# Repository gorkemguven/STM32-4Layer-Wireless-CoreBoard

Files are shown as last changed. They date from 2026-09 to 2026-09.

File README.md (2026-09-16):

# STM32 4-Layer Wireless Core Board

A compact, 4-layer reusable STM32 wireless core board designed in KiCad. It functions both as a standalone USB-to-Wireless dongle/sniffer and as a modular core block for integration into larger IoT and embedded carrier boards.

---

## 📌 Board Overview

| 3D / Top Layer View | Inner Ground Plane |
| :---: | :---: |
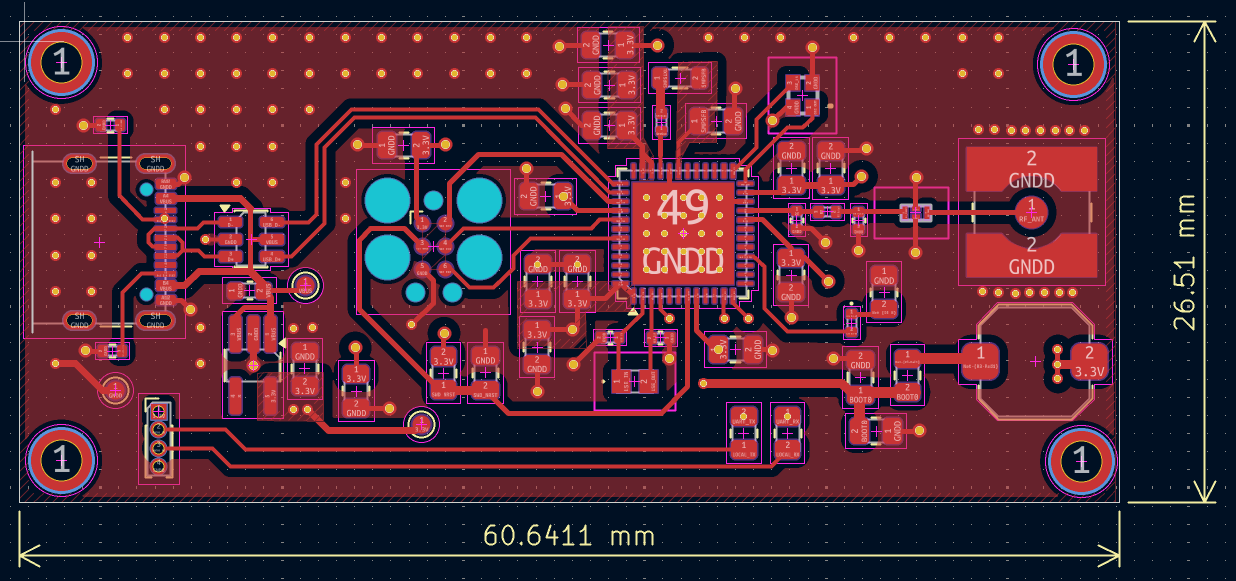
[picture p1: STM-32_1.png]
Top Layer
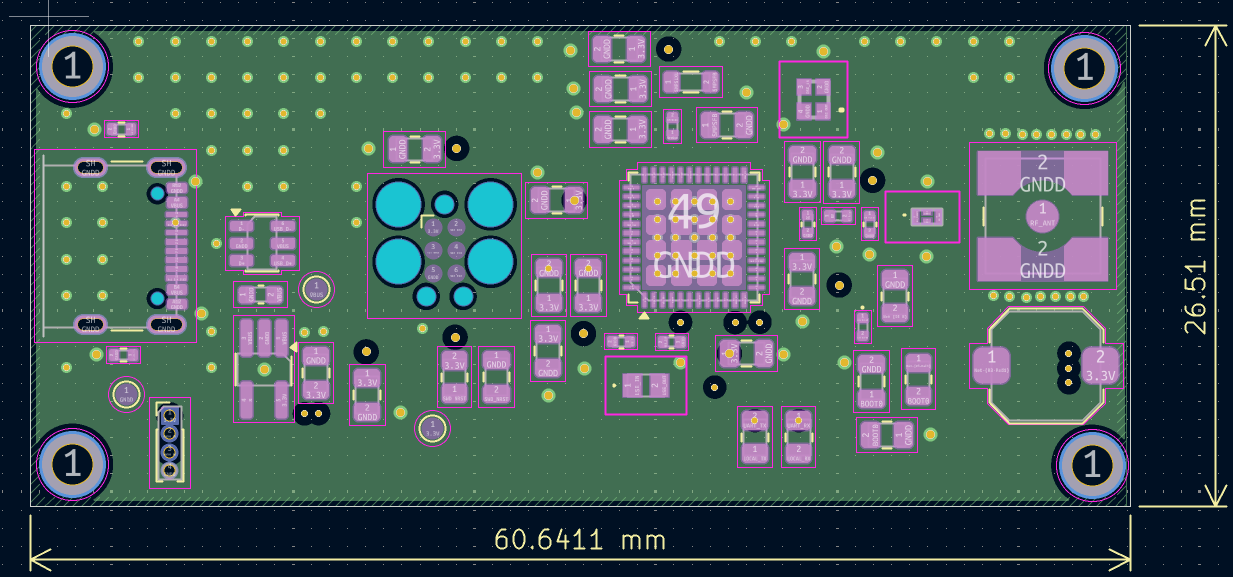
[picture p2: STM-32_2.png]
Inner GND
|  |  |

---

## 🚀 Key Features

* **MCU & Core:** STM32 microcontroller with integrated RF capabilities.
* **4-Layer Optimized Stackup:**
  * **Layer 1 (Top):** High-speed signals, RF trace, and localized GND polygon.
  * **Layer 2 (Inner 1):** Solid, unbroken Ground Reference Plane for signal integrity and RF return paths.
  * **Layer 3 (Inner 2):** Dedicated power plane split (3.3V and VBUS) optimized with Non-Functional Pad (NFP) removal to maximize copper pouring.
  * **Layer 4 (Bottom):** Auxiliary low-speed signal routing (UART TX/RX) and continuous GND shielding.
* **RF Architecture:**
  * 50 Ω impedance-matched microstrip line leading to antenna pad.
  * Perimeter and coplanar ground via stitching for minimal EMI and optimal shield performance.
* **Power Management:**
  * USB Type-C input with CC1/CC2 pull-down configuration.
  * Electrostatic Discharge (ESD) protection IC (`USBLC6-2SC6`) on differential USB data lines.
  * Low-noise, low-dropout linear regulator (`AP2112K-3.3V`, up to 600 mA).
* **Interfaces & Debugging:**
  * Dedicated Serial Wire Debug (SWD) test pad group for programming and hardware breakpoints.
  * Hardware `NRST` and `BOOT0` selection pads.
  * UART interface (`LOCAL_TX` / `LOCAL_RX`) with 220 Ω series current-limiting resistors for real-time logging.

---

## 📐 Schematic Sheets

| Sheet 1: MCU & RF Core | Sheet 2: Type-C & LDO Power |
| :---: | :---: |
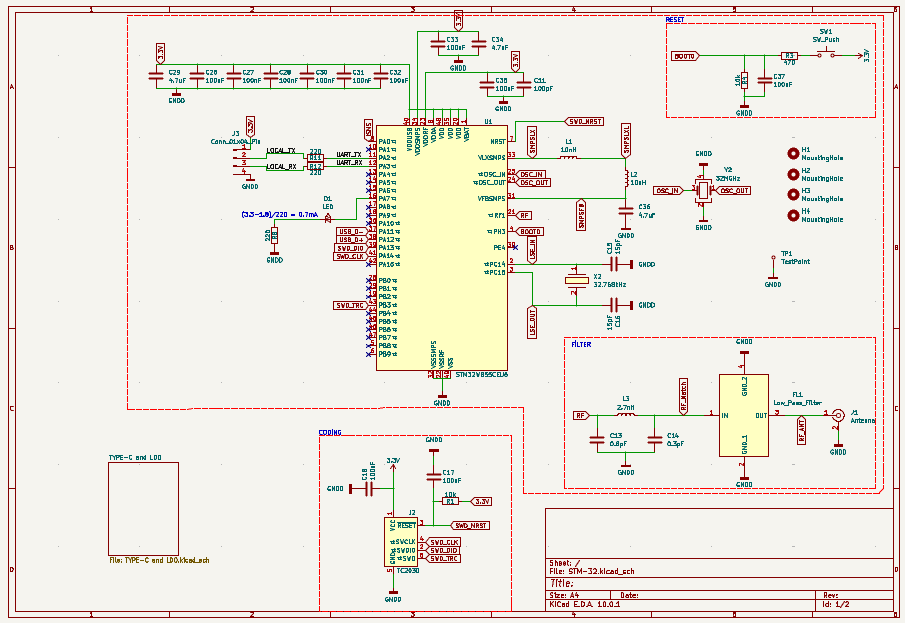
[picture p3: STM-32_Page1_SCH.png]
MCU Schematic
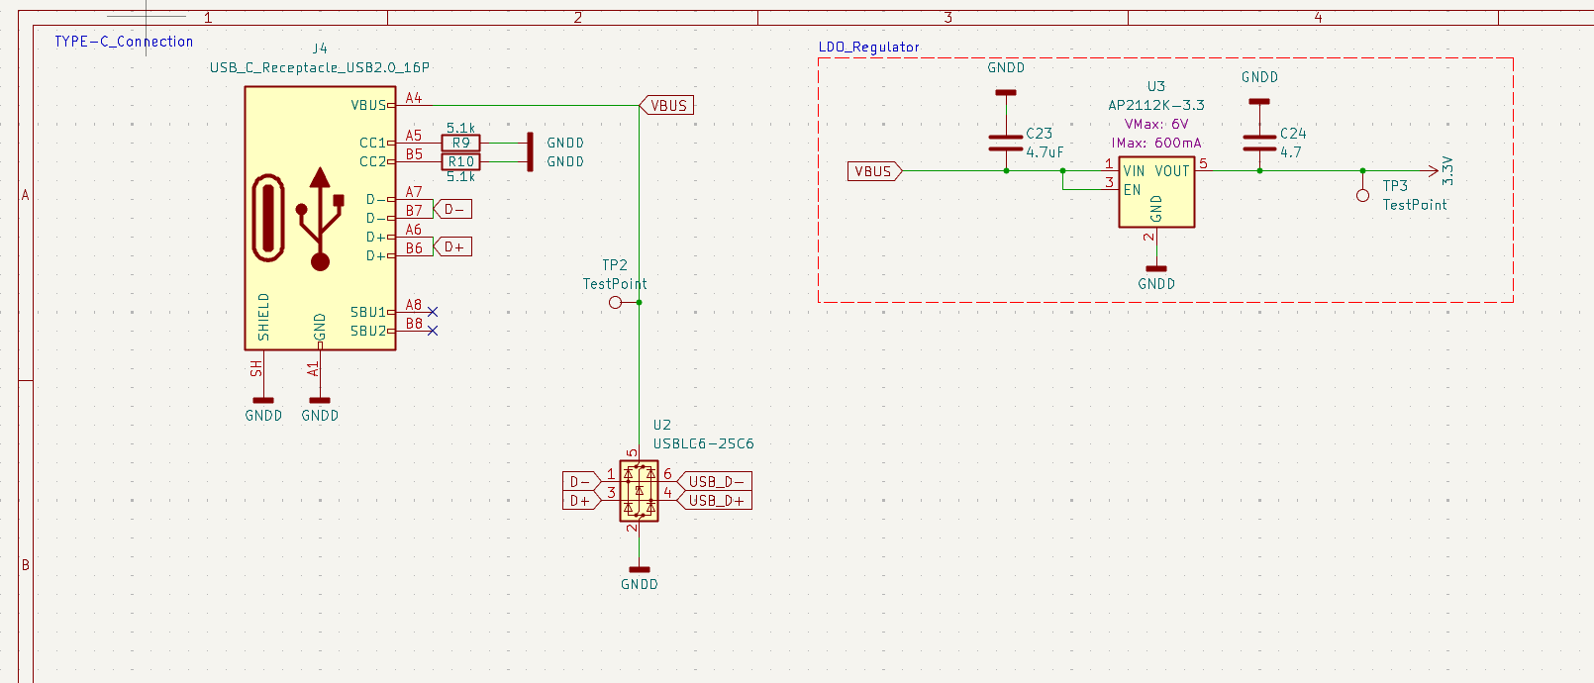
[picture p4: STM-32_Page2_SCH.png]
Power Schematic
|  |  |

---

## 🗂️ Layer Stackup Details

| Layer 1: Top Signal / GND | Layer 2: Inner Full GND |
| :---: | :---: |
| Top Layer | Inner GND |

| Layer 3: Inner Power (VBUS & 3.3V) | Layer 4: Bottom Signal / GND |
| :---: | :---: |
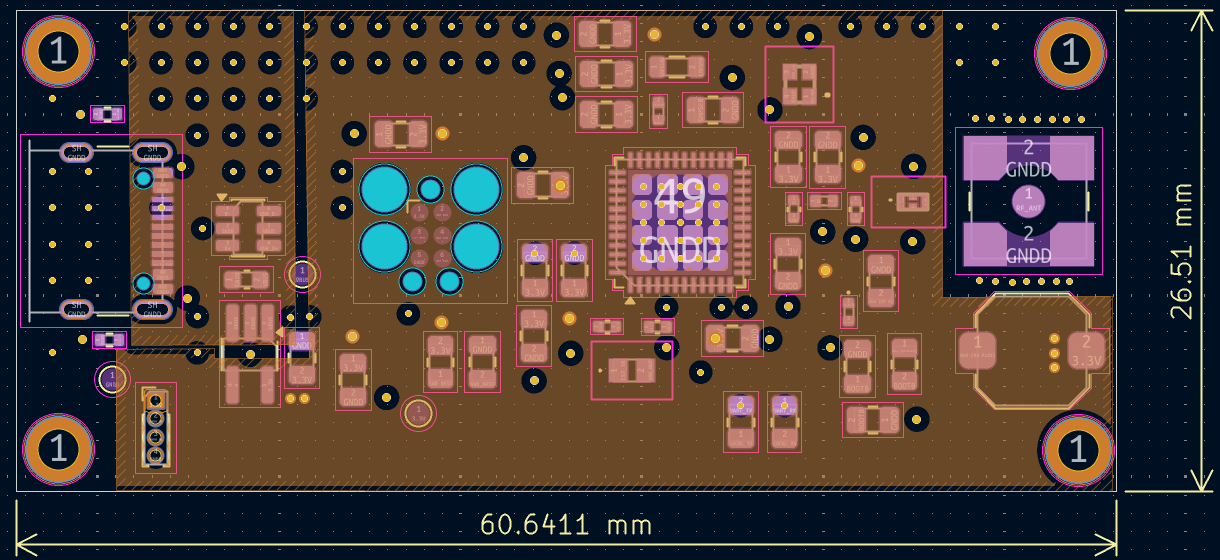
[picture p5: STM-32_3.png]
Inner Power
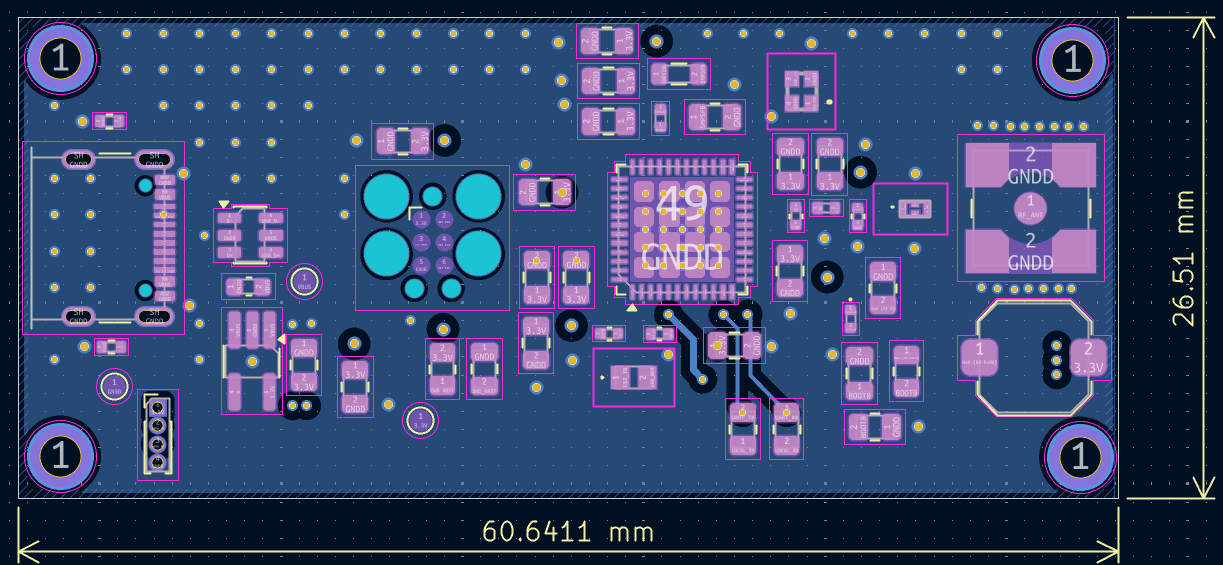
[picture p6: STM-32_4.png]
Bottom Layer
|  |  |

---

## 📦 Manufacturing & Assembly Files

All fabrication and assembly files are pre-generated and ready for fabrication (JLCPCB, PCBWay, etc.):

* **Gerber & Drill Package:** [`STM-32_Gerber.zip`](STM-32_Gerber.zip)
* **Bill of Materials (BOM):** [`bom.csv`](bom.csv)
* **Component Placement (CPL / Centroid):** [`positions.csv`](positions.csv)
* **Designators:** [`designators.csv`](designators.csv)
* **Netlist IPC:** [`netlist.ipc`](netlist.ipc)

---

## 💻 Hardware Design Files

To open and modify the native project, open `STM-32.kicad_pro` using KiCad.

* `STM-32.kicad_pro`: KiCad project settings file
* `STM-32.kicad_sch`: Root schematic sheet
* `TYPE-C and LDO.kicad_sch`: Sub-sheet for power distribution
* `STM-32.kicad_pcb`: 4-layer PCB layout

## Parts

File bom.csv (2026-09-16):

Designator | Footprint | Quantity | Value | LCSC Part #
C11 | 0805 | 1 | 100pF
C13 | 0402 | 1 | 0.8pF
C14 | 0402 | 1 | 0.3pF
C15, C16 | 0402 | 2 | 15pF
C17, C18, C23_2, C26, C27, C28, C30, C31, C32, C33, C35, C37 | 0805 | 12 | 100nF
C23 | 0603 | 1 | 4.7uF
C24 | 0805 | 1 | 4.7
C29, C34, C36 | 0805 | 3 | 4.7uF
D1 | 0402 | 1 | LED
FL1 | DLF162500LT5028A1 | 1 | Low_Pass_Filter
J1 | SMA_Wurth_60312102114405_Vertical | 1 | Antenna
J3 | PinHeader_1x04_P1.00mm_Vertical | 1 | Conn_01x04_Pin
J4 | USB_C_Receptacle_GCT_USB4105-xx-A_16P_TopMnt_Horizontal | 1 | USB_C_Receptacle_USB2.0_16P
L1 | 0402 | 1 | 10nH
L2 | 0805 | 1 | 10uH
L3 | 0402 | 1 | 2.7nH
R1, R4 | 0805 | 2 | 10k
R10, R9 | 0402 | 2 | 5.1k
R11, R12, R8 | 0805 | 3 | 220
R3 | 0805 | 1 | 470
SW1 | SW_Push_1TS009xxxx-xxxx-xxxx_6x6x5mm | 1 | SW_Push
TP1, TP2, TP3 | TestPoint_Pad_D1.0mm | 3 | TestPoint
U1 | QFN-48-1EP_7x7mm_P0.5mm_EP5.6x5.6mm | 1 | STM32WB55CEU6
U2 | SOT-23-6 | 1 | USBLC6-2SC6
U3 | TSOT-23-5_HandSoldering | 1 | AP2112K-3.3
X2 | NX2012SA32768KHZEXS00AMU00797 | 1 | 32.768kHz
Y2 | NX2016SA32MHZEXS00ACS06654 | 1 | 32MGHz

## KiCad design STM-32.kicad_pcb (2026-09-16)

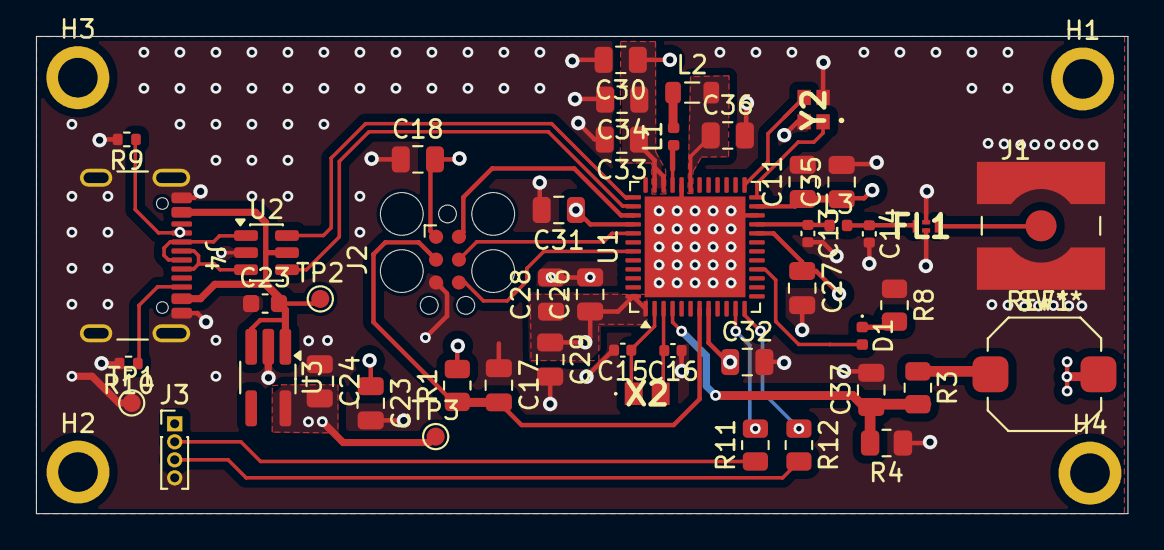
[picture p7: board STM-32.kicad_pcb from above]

Board: 4 copper layers, 60.6 x 26.5 mm, 52 parts (0 on the bottom side), 31 nets.

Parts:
C11: 100pF; C_0805_2012Metric
C13: 0.8pF; C_0402_1005Metric
C14: 0.3pF; C_0402_1005Metric
C15, C16: 15pF; C_0402_1005Metric
C17, C18, C23, C26, C27, C28, C30, C31, C32, C33, C35, C37: 100nF; C_0805_2012Metric
C23#2: 4.7uF; C_0603_1608Metric
C24: 4.7; C_0805_2012Metric
C29, C34, C36: 4.7uF; C_0805_2012Metric
D1: LED; LED_0402_1005Metric
FL1: Low_Pass_Filter; DLF162500LT5028A1
H1, H2, H3, H4: MountingHole; MountingHole_2.2mm_M2_ISO7380_Pad
J1: Antenna; SMA_Wurth_60312102114405_Vertical
J2: TC2030; Tag-Connect_TC2030-IDC-FP_2x03_P1.27mm_Vertical
J3: Conn_01x04_Pin; PinHeader_1x04_P1.00mm_Vertical
J4: USB_C_Receptacle_USB2.0_16P; USB_C_Receptacle_GCT_USB4105-xx-A_16P_TopMnt_Horizontal
L1: 10nH; L_0402_1005Metric
L2: 10uH; L_0805_2012Metric
L3: 2.7nH; L_0402_1005Metric
R1, R4: 10k; R_0805_2012Metric
R3: 470; R_0805_2012Metric
R8, R11, R12: 220; R_0805_2012Metric
R9, R10: 5.1k; R_0402_1005Metric
SW1: SW_Push; SW_Push_1TS009xxxx-xxxx-xxxx_6x6x5mm
TP1, TP2, TP3: TestPoint; TestPoint_Pad_D1.0mm
U1: STM32WB55CEU6; QFN-48-1EP_7x7mm_P0.5mm_EP5.6x5.6mm
U2: USBLC6-2SC6; SOT-23-6
U3: AP2112K-3.3; TSOT-23-5_HandSoldering
X2: 32.768kHz; NX2012SA32768KHZEXS00AMU00797
Y2: 32MGHz; NX2016SA32MHZEXS00ACS06654

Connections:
3.3V: C11.1, C18.2, C23.1, C24.2, C26.1, C27.1, C28.1, C29.1, C30.1, C31.1, C32.1, C33.1, C34.1, C35.1, J2.1 (VCC), J3.1, R1.2, SW1.2, TP3.1 (1_1), U1.1 (VBAT), U1.8 (VDDA), U1.20 (VDD), U1.23 (VDDRF), U1.34 (VDDSMPS), U1.35 (VDD), U1.40 (VDDUSB), U1.48 (VDD), U3.5 (VOUT)
/LOCAL_RX: J3.3, R12.2
/LOCAL_TX: J3.2, R11.1
/UART_RX: R12.1, U1.12 (PA3)
/UART_TX: R11.2, U1.11 (PA2)
BOOT0: C37.1, R3.2, R4.2, U1.4 (PH3)
D+: J4.A6 (D+), J4.B6 (D+), U2.3 (I/O2)
D-: J4.A7 (D-), J4.B7 (D-), U2.1 (I/O1)
GNDD: C11.2, C13.2, C14.2, C15.2, C16.1, C17.1, C18.1, C23.2, C23#2.1, C24.1, C26.2, C27.2, C28.2, C29.2, C30.2, C31.2, C32.2, C33.2, C34.2, C35.2, C36.2, C37.2, FL1.2 (GND_1), FL1.4 (GND_2), J1.2 (Ext), J2.5 (GND), J3.4, J4.A1 (GND), J4.A12 (GND), J4.B1 (GND), J4.B12 (GND), J4.SH (SHIELD), R4.1, R8.1, R9.2, R10.2, TP1.1 (1_1), U1.22 (VSSRF), U1.32 (VSSSMPS), U1.49 (VSS), U2.2 (GND), U3.2 (GND), Y2.2 (3), Y2.4 (2)
LSE_IN: C15.1, U1.2 (PC14), X2.1 (CRYSTAL_2)
LSE_OUT: C16.2, U1.3 (PC15), X2.2 (CRYSTAL_2)
unnamed: D1.2 (A), U1.16 (PA7)
unnamed: D1.1 (K), R8.2
unnamed: J4.A5 (CC1), R9.1
unnamed: J4.B5 (CC2), R10.1
unnamed: R3.1, SW1.1
OSC_IN: U1.25 (OSC_IN), Y2.3 (1)
OSC_OUT: U1.24 (OSC_OUT), Y2.1 (4)
RF: C13.1, L3.1, U1.21 (RF1)
RF_ANT: FL1.3 (OUT), J1.1 (In)
RF_Match: C14.1, FL1.1 (IN), L3.2
SMPSFB: C36.1, L2.2, U1.31 (VFBSMPS)
SMPSLX: L1.1, U1.33 (VLXSMPS)
SMPSLXL: L1.2, L2.1
SWD_CLK: J2.4 (SWCLK), U1.41 (PA14)
SWD_DIO: J2.2 (SWDIO), U1.39 (PA13)
SWD_NRST: C17.2, J2.3 (~RESET), R1.1, U1.7 (NRST)
SWD_TRC: J2.6 (SWO), U1.43 (PB3)
USB_D+: U1.38 (PA12), U2.4 (I/O2)
USB_D-: U1.37 (PA11), U2.6 (I/O1)
VBUS: C23#2.2, J4.A4 (VBUS), J4.A9 (VBUS), J4.B4 (VBUS), J4.B9 (VBUS), TP2.1 (1_1), U2.5 (VBUS), U3.1 (VIN), U3.3 (EN)
